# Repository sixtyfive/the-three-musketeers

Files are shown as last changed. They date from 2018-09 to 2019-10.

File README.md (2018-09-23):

I needed something to feed three audio sources into my amplifier's AUX input. I also wanted to learn how to design a simple schematic and PCB with Eagle. As a power source I wanted to be able to use any USB port, so the power supply schematic turned out more complex than the actual thing.

Anyways, that's it.

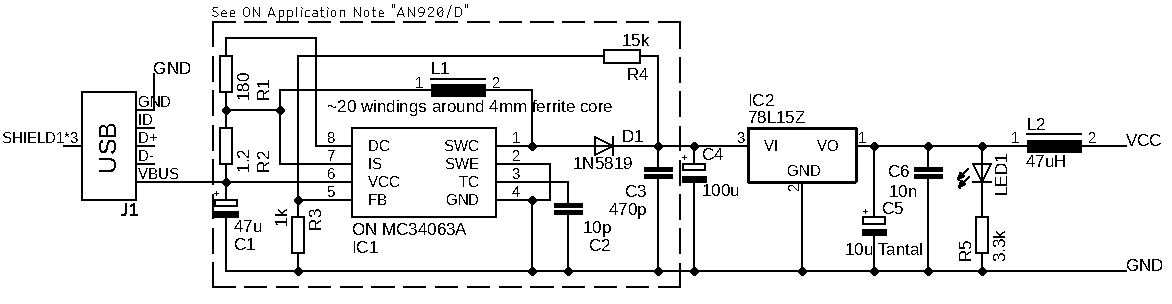
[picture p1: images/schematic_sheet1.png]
Schematic, sheet 1


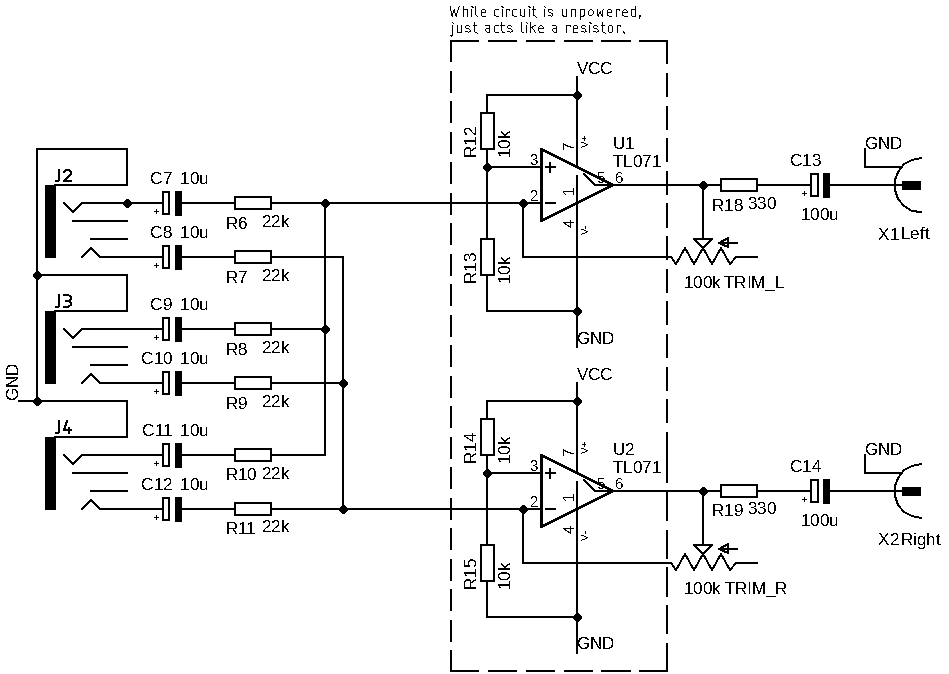
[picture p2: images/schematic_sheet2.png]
Schematic, sheet 2


Careful with the PCB, the current version hasn't been made yet.

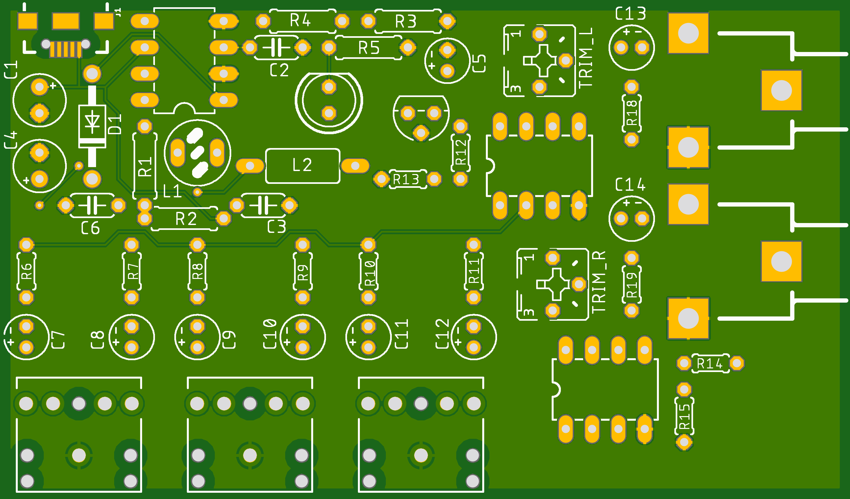
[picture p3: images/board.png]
PCB


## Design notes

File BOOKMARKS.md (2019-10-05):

- http://musicfromouterspace.com/analogsynth_new/WALLWARTSUPPLY/WALLWARTSUPPLY.php
- https://www.sequencer.de/synthesizer/threads/symmetrische-spannung-aus-trafo-ohne-mittelanzapfung.40293/
- https://www.sowter.co.uk/rectifier-transformer-calculation.php
- http://6.qvsbwedkl.aboutlaura.de/circuit-description-the-preamp-circuit-based-on-a-design-in-the-1975.html
  - http://www.next.gr/uploads/8/pre-amp-single-supply.jpg
- https://www.elcircuit.com/2016/09/hifi-audio-preamp-circuit-tl072.html?m=1
  - https://2.bp.blogspot.com/-1wqxx-jvaGM/V-nGi2WOsvI/AAAAAAAAA0s/gCCoJ27efYsKQ02fjROY2QzsP2jolWZbACLcB/s640/HiFi%2BPreAmp%2BCircuit%2BSchematic.jpg
- https://sound-au.com/project163.htm
- https://sound-au.com/project37.htm
- http://www.qrp4u.de/docs/en/agc_sm/index.htm
- https://hackaday.io/project/46280-muffsy-stereo-relay-input-selector
- http://i.imgur.com/gPQodsj.gif (diode compressor! cool! formulas?)
- https://www.electroschematics.com/wp-content/uploads/2013/12/Update-Audio-Compressor-AGC-Schematic-2.jpg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

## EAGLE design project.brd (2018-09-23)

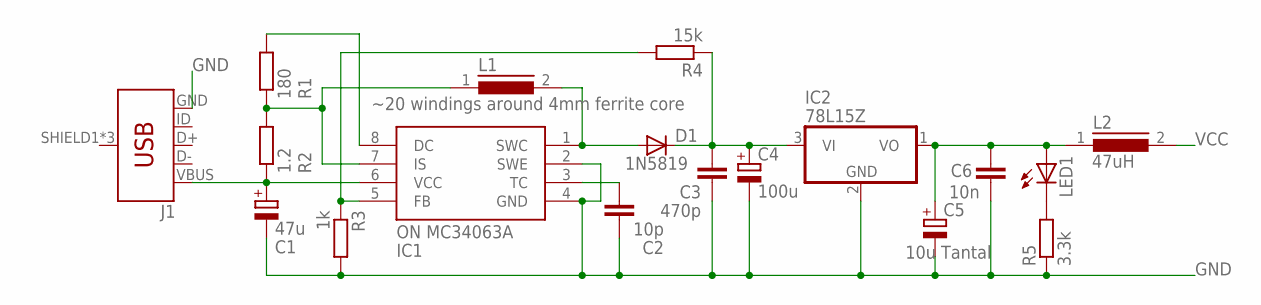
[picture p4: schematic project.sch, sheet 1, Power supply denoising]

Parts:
C1: 47u; E2,5-5
C2: 10p; C050-024X044
C3: 470p; C050-024X044
C4: 100u; E2,5-5
C5: 10u Tantal; E2-4
C6: 10n; C050-024X044
D1: 1N5819; DO41-10
IC1: ON MC34063A; DIL08
IC2: 78L15Z; TO92
J1: USB_MICRO-B_FEMALE-SMT; USB-B-MICRO-SMD
L1: ~20 windings around 4mm ferrite core; 82114R
L2: 47uH; MCC10
LED1: LED5MM
R1: 180; 0207/7
R2: 1.2; 0207/7
R3: 1k; 0207/7
R4: 15k; 0207/7
R5: 3.3k; 0207/7

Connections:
GND: C1.-, C2.1, C3.1, C4.-, C5.-, C6.1, IC1.2 (SWE), IC1.4 (GND), IC2.2 (GND), R3.2, R5.1; also elsewhere on the board
unnamed: IC1.8 (DC), R1.2
unnamed: D1.A, IC1.1 (SWC), L1.2
unnamed: C5.+, C6.2, IC2.1 (VO), L2.1, LED1.A
unnamed: C3.2, C4.+, D1.C, IC2.3 (VI), R4.1
unnamed: LED1.K (C), R5.2
unnamed: C2.2, IC1.3 (TC)
unnamed: IC1.5 (FB), R3.1, R4.2
unnamed: C1.+, IC1.6 (VCC), J1.VBUS, R2.1
unnamed: IC1.7 (IS), L1.1, R1.1, R2.2
VCC: L2.2; also elsewhere on the board

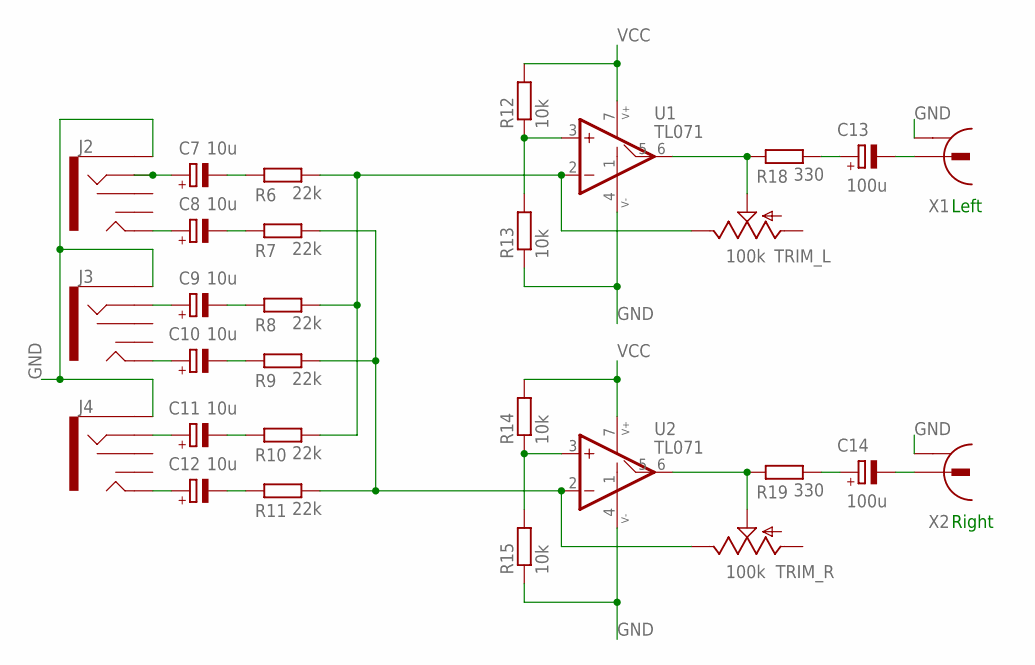
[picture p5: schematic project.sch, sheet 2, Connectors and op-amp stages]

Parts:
C7, C8, C9, C10, C11, C12: 10u; E2-4
C13, C14: 100u; E2-4
J2, J3, J4: AUDIO_JACK_3.5MM_KIT; AUDIO-JACK-KIT
R6, R7, R8, R9, R10, R11: 22k; 0204/5
R12, R13, R14, R15: 10k; 0204/5
R18, R19: 330; 0204/5
TRIM_L: 100k; B25P
TRIM_R: 100k; B25P
U1, U2: TL071; DIL08
X1, X2: CONRAD_736880-49; CINCH

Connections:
GND: J2.SLEEVE, J3.SLEEVE, J4.SLEEVE, R13.1, R15.1, U1.4 (V-), U2.4 (V-), X1.2, X2.2; also elsewhere on the board
unnamed: C13.-, X1.1
unnamed: C13.+, R18.2
unnamed: C14.-, X2.1
unnamed: C7.-, R6.1
unnamed: R18.1, TRIM_L.S, U1.6 (OUT)
unnamed: C14.+, R19.2
unnamed: C7.+, J2.RING
unnamed: R12.1, R13.2, U1.3 (+IN)
unnamed: C8.+, J2.TIP
unnamed: R6.2, R8.2, R10.2, TRIM_L.E, U1.2 (-IN)
unnamed: C8.-, R7.1
unnamed: C9.+, J3.RING
unnamed: C9.-, R8.1
unnamed: C10.+, J3.TIP
unnamed: C10.-, R9.1
unnamed: C11.+, J4.RING
unnamed: C11.-, R10.1
unnamed: C12.+, J4.TIP
unnamed: C12.-, R11.1
unnamed: R19.1, TRIM_R.S, U2.6 (OUT)
unnamed: R14.1, R15.2, U2.3 (+IN)
unnamed: R7.2, R9.2, R11.2, TRIM_R.E, U2.2 (-IN)
VCC: R12.2, R14.2, U1.7 (V+), U2.7 (V+); also elsewhere on the board

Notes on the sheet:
Left
Right

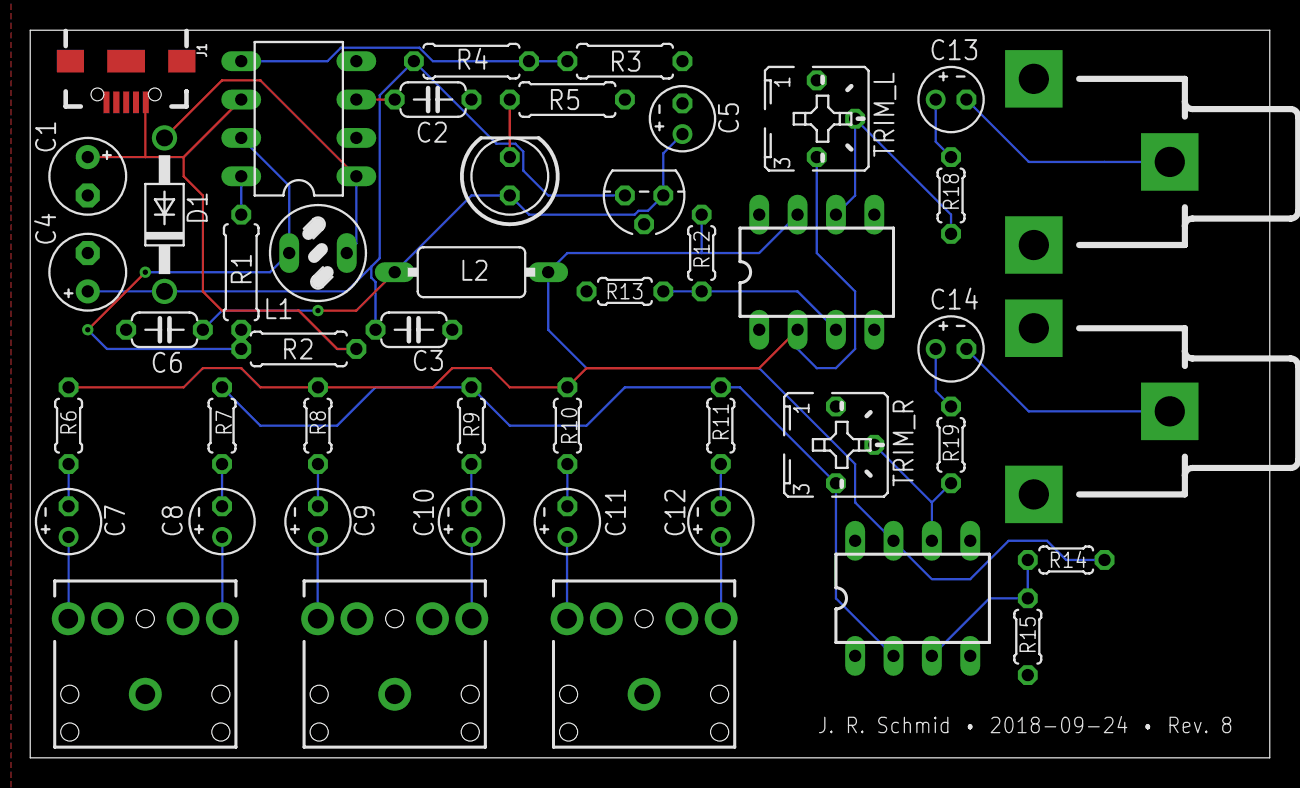
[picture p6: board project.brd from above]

Board: 2 copper layers, 82.1 x 48.2 mm, 47 parts (0 on the bottom side), 33 nets.

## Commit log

2018-07-21 Initial import: schema and board.
    [power.brd, power.sch]
2018-07-21 Moving bDocu contents slightly
    [power.brd]
2018-07-21 Adding Gerber rules
2018-07-21 Ignore Gerber files.
2018-07-21 Moving labels to (t,b)Place
    [power.brd]
2018-07-21 Updating Rev label
    [power.brd]
2018-07-21 Removing unneeded info from schematic
    [power.sch]
2018-07-21 Cleaning up part designation locations
    [power.brd]
2018-07-21 Renaming to something generic
    [project.brd, project.sch]
2018-07-21 Minor positioning adjustments
    [project.brd]
2018-07-21 Bumping revision
    [project.brd]
2018-07-21 Updating screenshots
    [project.sch]
2018-08-13 Fixing all bugs thus far that were in the schematic. PCB layout now broken!
    [project.brd, project.sch]
2018-09-22 Updating with new power supply Rev.
    [project.brd, project.sch]
2018-09-23 Updating to latest prototype revision.
    [project.brd, project.sch]
2018-09-23 Updating from latest schematic.
2018-09-23 Re-doing the PCB.
    [project.brd]
2019-10-05 Adding AGC circuits

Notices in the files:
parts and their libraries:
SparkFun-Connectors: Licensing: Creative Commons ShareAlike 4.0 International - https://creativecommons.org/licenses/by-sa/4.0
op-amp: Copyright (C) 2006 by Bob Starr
